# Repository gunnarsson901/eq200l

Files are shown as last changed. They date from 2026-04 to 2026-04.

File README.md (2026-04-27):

```
  ███████╗ ██████╗    ██████╗  ██████╗  ██████╗ ██╗     
  ██╔════╝██╔═══██╗  ╚════██╗██╔═══██╗██╔═══██╗██║     
  █████╗  ██║   ██║   █████╔╝██║   ██║██║   ██║██║     
  ██╔══╝  ██║▄▄ ██║  ██╔═══╝ ██║   ██║██║   ██║██║     
  ███████╗╚██████╔╝  ███████╗╚██████╔╝╚██████╔╝███████╗
  ╚══════╝ ╚══▀▀═╝   ╚══════╝ ╚═════╝  ╚═════╝ ╚══════╝
                 Passive Ethernet Network Tap
```

---

## Introduction

**EQ200L** is a hardware + firmware project for building a passive, transparent Ethernet network tap. Traffic flowing between two network endpoints passes through the device unmodified. The FPGA sits in-line, captures a copy of every frame in both directions, and feeds it to a Raspberry Pi for processing and analysis.

The system uses LAN8720 PHY breakouts for Ethernet connectivity, exposes a menu-driven OLED interface on the Pi, and includes a LoRa radio link for wireless data relay.

**Hardware progression:**

| Stage | FPGA | Host Pi | Notes |
|---|---|---|---|
| Testing | Olimex iCE40HX8K-EVB | Pi Zero 2W | Pi Zero 2W RAM too limited for on-device builds |
| **Current** | **iCeSugar Pro (ECP5)** | **Raspberry Pi 4** | Build and flash from Pi 4 over USB |
| Target | iCeSugar Pro (ECP5) | CM4 8GB, 0GB eMMC | Final embedded form factor |

---

## File Tree

```
eq200l/
├── README.md                         ← you are here
│
├── ICE/                              ← FPGA designs & toolchain
│   ├── install.sh                    ← toolchain installer
│   ├── requirements.txt              ← Python deps for build scripts
│   ├── lib/                          ← reusable Verilog modules
│   │   ├── async_fifo.v
│   │   ├── bram_fifo.v
│   │   ├── cdc_sync.v
│   │   ├── rmii_rx.v                 ← RMII dibit → byte stream
│   │   ├── rmii_tx.v                 ← byte stream → RMII dibit
│   │   ├── spi_slave.v               ← SPI interface to Pi
│   │   ├── sync_fifo.v
│   │   └── uart_tx.v
│   │
│   ├── olimex-ice40hx8k/             ← iCE40HX8K-EVB board target
│   │   ├── hw/                       ← basic design: RMII rx → UART tx
│   │   │   ├── src/top.v
│   │   │   ├── top.pcf
│   │   │   └── Makefile
│   │   ├── sim/                      ← testbench for hw/
│   │   │   ├── src/  tb/  sim/
│   │   │   └── Makefile
│   │   └── projects/
│   │       ├── blink_button/
│   │       ├── spi_message/          ← SPI comms demo
│   │       └── eq200l/               ← dual-port tap (main project)
│   │           ├── src/
│   │           ├── top.pcf
│   │           └── Makefile
│   │
│   └── icesugar-pro/                 ← ECP5 iCeSugar Pro board target
│       ├── hw/                       ← 25 MHz single-clock tap
│       │   ├── src/top.v
│       │   ├── top.lpf
│       │   └── Makefile
│       ├── sim_tap/                  ← full tap sim with SMI interface
│       │   ├── src/  tb/
│       │   └── Makefile
│       └── docs/
│           ├── README.md             ← SODIMM-200P pinout table
│           └── wiring.md             ← LAN8720 ↔ FPGA connections
│
├── PI/                               ← Raspberry Pi software
│   └── interface/                    ← OLED menu UI
│       ├── main.py                   ← scrollable menu application
│       ├── display.py                ← SSD1309 I2C driver
│       ├── buttons.py                ← GPIO button polling + debounce
│       ├── requirements.txt          ← luma.oled, RPi.GPIO, Pillow
│       └── TEST/                     ← unit tests
│
├── LoRa/                             ← LoRa wireless subsystem
│   ├── lora_terminal.py              ← UART ↔ LoRa bridge terminal
│   ├── probe.py                      ← DX-LR20 chip probe utility
│   └── docs/                         ← datasheets & module info
│
└── docs/                             ← hardware documentation
    ├── eq200l schematics/            ← project schematics
    ├── icesugar-pro/                 ← ECP5 board docs & pinout image
    ├── ice40hx8k/                    ← iCE40 board docs
    ├── LAN8720 ETH Board/            ← PHY datasheet
    ├── LoRa/                         ← LoRa module docs
    └── examen arbete YRGO/           ← exam work archive
```

---

## System Flow

```mermaid
flowchart LR
    A([Port A\nRJ45]) <-->|Ethernet| PHY_A[LAN8720\nPHY A]
    B([Port B\nRJ45]) <-->|Ethernet| PHY_B[LAN8720\nPHY B]

    PHY_A <-->|RMII| FPGA
    PHY_B <-->|RMII| FPGA

    subgraph FPGA [FPGA  iCE40 / ECP5]
        direction TB
        FWD[Transparent\nForwarding]
        BUF[(Frame\nCapture FIFO)]
        FWD -->|tap copy| BUF
    end

    FPGA <-->|SPI / SMI| PI[Raspberry Pi 4\n→ CM4 target]

    PI --> OLED[SSD1309\nOLED 128×64]
    PI <-->|GPIO| BTN[5-Button\nNavpad]
    PI <-->|UART| LORA[DX-LR20\nLoRa 433 MHz]

    LORA -.->|wireless| REMOTE([Remote Node])
```

---

## Features

### FPGA Core

| Feature | Status |
|---|---|
| Transparent dual-port Ethernet forwarding | Implemented |
| RMII frame capture — iCE40HX8K target | Implemented |
| RMII frame capture — ECP5 iCeSugar Pro target | Implemented |
| Frame capture FIFO (BRAM-backed) | Implemented |
| Packet filtering in FPGA | TBI |

### Host Interface

| Feature | Status |
|---|---|
| UART frame output to host | Implemented |
| SPI slave interface to Pi | Implemented |
| SMI high-bandwidth interface to Pi | TBI |
| SMI DMA burst transfers | TBI |

### Toolchain & Build

| Feature | Status |
|---|---|
| FPGA flash via Pi SPI + flashrom (iCE40) | Implemented |
| FPGA flash via openFPGALoader (ECP5) | Implemented |
| iverilog simulation + GTKWave waveforms | Implemented |
| ice.sh CLI workflow menu | Implemented |

### User Interface

| Feature | Status |
|---|---|
| SSD1309 OLED menu UI (128×64, I2C) | Implemented |
| 5-button navigation with debounce | Implemented |
| Web interface for captured traffic | TBI |

### Wireless

| Feature | Status |
|---|---|
| LoRa UART bridge terminal | Implemented |
| LoRa chip probe / configuration utility | Implemented |
| Wireless streaming of captures via LoRa | TBI |

### Software / Analysis

| Feature | Status |
|---|---|
| Pi-side frame decoder / pcap export | TBI |

### Hardware Platform

| Milestone | Status |
|---|---|
| iCE40HX8K-EVB + Pi Zero 2W (initial testing) | Implemented |
| iCeSugar Pro (ECP5) + Raspberry Pi 4 (current) | Implemented |
| CM4 8GB RAM, 0GB eMMC — final form factor | TBI |

---

## Devices

### FPGA — iCeSugar Pro (ECP5) — *current board*

Lattice ECP5 FPGA on a compact module with a DDR-SODIMM-200P edge connector and a
built-in iCELink DAPLink USB adapter (`0x0d28:0x0204`). Programmed via
`openFPGALoader --cable cmsisdap` directly from the Pi 4 over USB — no SPI
programmer needed.

## DDR-SODIMM-200P
| Function | Top-Pin | Bot-Pin | Function |
|---|---|---|---|
| GND | 1 | 2 | 5V |
| GND | 3 | 4 | 5V |
| GND | 5 | 6 | 5V |
| GND | 7 | 8 | 5V |
| GND | 9 | 10 | 5V |
| GND | 11 | 12 | 5V |
| NC | 13 | 14 | NC |
| NC | 15 | 16 | NC |
| NC | 17 | 18 | NC |
| NC | 19 | 20 | NC |
| NC | 21 | 22 | NC |
| NC | 23 | 24 | NC |
| NC | 25 | 26 | NC |
| NC | 27 | 28 | NC |
| NC | 29 | 30 | NC |
| NC | 31 | 32 | NC |
| NC | 33 | 34 | NC |
| NC | 35 | 36 | NC |
| NC | 37 | 38 | NC |
| GND | 39 | 40 | GND |
| | | | |
| | | | |
| A8 | 41 | 42 | P11 |
| NC | 43 | 44 | P12 |
| NC | 45 | 46 | N12 |
| NC | 47 | 48 | P13 |
| B8 | 49 | 50 | N13 |
| A7 | 51 | 52 | P14 |
| NC | 53 | 54 | M12 |
| GND | 55 | 56 | GND |
| B7 | 57 | 58 | M13 |
| A6 | 59 | 60 | L14 |
| B6 | 61 | 62 | L13 |
| A5 | 63 | 64 | K14 |
| B5 | 65 | 66 | K13 |
| A4 | 67 | 68 | J14 |
| B4 | 69 | 70 | J13 |
| A3 | 71 | 72 | H14 |
| B3 | 73 | 74 | H13 |
| A2 | 75 | 76 | G14 |
| B1 | 77 | 78 | G13 |
| B2 | 79 | 80 | F14 |
| C1 | 81 | 82 | F13 |
| C2 | 83 | 84 | E14 |
| D1 | 85 | 86 | E13 |
| D3 | 87 | 88 | E12 |
| E1 | 89 | 90 | C13 |
| E2 | 91 | 92 | D13 |
| F1 | 93 | 94 | C12 |
| F2 | 95 | 96 | D12 |
| G1 | 97 | 98 | C11 |
| G2 | 99 | 100  | D11 |
| H2 | 101  | 102  | C10 |
| J1 | 103  | 104  | D10 |
| GND | 105  | 106  | GND |
| GND | 107  | 108  | GND |
| J2 | 109  | 110  | C9 |
| K1 | 111  | 112  | D9 |
| K2 | 113  | 114  | C8 |
| L1 | 115  | 116  | D8 |
| L2 | 117  | 118  | C7 |
| M1 | 119  | 120  | D7 |
| M2 | 121  | 122  | C6 |
| N1 | 123  | 124  | D6 |
| N3 | 125  | 126  | C5 |
| P1 | 127  | 128  | D5 |
| P2 | 129  | 130  | C4 |
| R1 | 131  | 132  | D4 |
| R2 | 133  | 134  | C3 |
| T2 | 135  | 136  | E4 |
| R3 | 137  | 138  | E3 |
| T3 | 139  | 140  | F4 |
| R4 | 141  | 142  | F3 |
| T4 | 143  | 144  | G4 |
| R5 | 145  | 146  | G3 |
| R6 | 147  | 148  | H3 |
| T6 | 149  | 150  | J4 |
| P7 | 151  | 152  | J3 |
| R7 | 153  | 154  | K4 |
| R8 | 155  | 156  | K3 |
| GND | 157  | 158  | GND |
| NC | 159  | 160  | NC |
| NC | 161  | 162  | NC |
| NC | 163  | 164  | NC |
| NC | 165  | 166  | NC |
| NC | 167  | 168  | NC |
| NC | 169  | 170  | NC |
| NC | 171  | 172  | NC |
| NC | 173  | 174  | NC |
| NC | 175  | 176  | NC |
| NC | 177  | 178  | NC |
| NC | 179  | 180  | NC |
| NC | 181  | 182  | NC |
| NC | 183  | 184  | NC |
| NC | 185  | 186  | NC |
| NC | 187  | 188  | NC |
| NC | 189  | 190  | NC |
| NC | 191  | 192  | NC |
| NC | 193  | 194  | NC |
| NC | 195  | 196  | NC |
| NC | 197  | 198  | NC |
| GND | 199  | 200  | GND |

## Ext-Board Pin map
the Ext-Board is origin designed for Colorlight i5 module, in [Colorlight-FPGA-Projects](https://github.com/wuxx/Colorlight-FPGA-Projects), there is a on-board DAPLink to do the flash work, the iCESugar-Pro doesn't need it, so the Ext-Board actually is a "real" breakout board.  
iCESugar-pro-pinmap

### Notes
Please note that some pins of P5 are shared with Ext-Board DAPLink, include {D12, C11, D13, C12, E12, C13, E14, E13}, if you have enough pins, just don't use these pins. if you want to use these pins, one simple way is force the Ext-Board DAPLink run into bootloader. just create a file named `START_BL.ACT` in root directory of DAPLink. for example, type `$cd /media/pi/DAPLink && touch START_BL.ACT`

> `icesprog` does **not** work with the iCELink firmware — it expects VID `0x1d50`.
> Use `openFPGALoader` instead.

**Toolchain:** `yosys` → `nextpnr-ecp5` → `ecppack` → `openFPGALoader`

**udev rule (run once on the host Pi):**
```bash
sudo tee /etc/udev/rules.d/99-icesugar.rules <<'EOF'
SUBSYSTEM=="usb", ATTRS{idVendor}=="0d28", ATTRS{idProduct}=="0204", MODE="0666", GROUP="plugdev"
SUBSYSTEM=="hidraw", ATTRS{idVendor}=="0d28", ATTRS{idProduct}=="0204", MODE="0666", GROUP="plugdev"
EOF
sudo udevadm control --reload-rules && sudo udevadm trigger
```

See [`ICE/icesugar-pro/docs/wiring.md`](ICE/icesugar-pro/docs/wiring.md) for LAN8720 ↔ ECP5 pin connections.

---

### FPGA — Olimex iCE40HX8K-EVB — *legacy / testing*

Used during initial development. Houses a Lattice iCE40HX8K in a CT256 BGA package.
Programmed via Pi SPI using `flashrom`; the same SPI lines double as the runtime
data path (`spi_slave.v`). Superseded by the iCeSugar Pro for active development.

**Toolchain:** `yosys` → `nextpnr-ice40` → `icepack` → `flashrom`

| Onboard signal | Net | FPGA pin |
|---|-----|---|
| 100 MHz clock | `CLK` | J3 |
| LED 1 | `LED1` | M12 |
| LED 2 | `LED2` | R16 |
| Button 1 | `BUT1` | K11 |
| Button 2 | `BUT2` | P13 |

**RMII connections (LAN8720 ↔ iCE40)**

| Signal | LAN8720 pin | Verilog net | FPGA pin |
|---|---|---|---|
| 50 MHz ref clock | nINT/RETCLK | `pio3_00` | E4 (GBIN) |
| RX data 0 | RXD0 | `pio3_01` | B2 |
| RX data 1 | RXD1 | `pio3_08` | G5 |
| Carrier sense | CRS_DV | `pio3_07` | D2 |
| TX enable | TX_EN | `pio3_02` | F5 |
| TX data 0 | TXD0 | `pio3_09` | D1 |
| TX data 1 | TXD1 | `pio3_03` | B1 |
| Management data | MDIO | `pio3_04` | C1 |
| Management clock | MDC | `pio3_06` | F4 |

**SMI interface (iCE40 ↔ Pi GPIO)**

| Signal | Pi GPIO (BCM) | Verilog net | FPGA pin |
|---|---|---|---|
| SMI Data 0 | 8 | `pio3_15` | F3 |
| SMI Data 1 | 9 | `pio3_16` | H3 |
| SMI Data 2 | 10 | `pio3_17` | F2 |
| SMI Data 3 | 11 | `pio3_18` | H6 |
| SMI Data 4 | 12 | `pio3_19` | F1 |
| SMI Data 5 | 13 | `pio3_20` | H4 |
| SMI Data 6 | 14 | `pio3_21` | G2 |
| SMI Data 7 | 15 | `pio3_22` | J4 |
| SMI Address 0 | 0 | `pio3_23` | G1 |
| SMI Address 1 | 1 | `pio3_24` | J3 |
| SMI Read (SOE) | 18 | `pio3_25` | G3 |
| SMI Write (SWE) | 19 | `pio3_26` | K3 |

---

### Ethernet PHY — LAN8720

Low-power 10/100 Ethernet transceiver in a small breakout module. Provides the
RMII interface (2-bit data, 50 MHz reference clock) between the RJ45 jack and
the FPGA. Two modules are used — one for each network port.

Key signals: `RXD[1:0]`, `CRS_DV`, `TXD[1:0]`, `TX_EN`, `REF_CLK`, `MDIO`, `MDC`.

---

### Host — Raspberry Pi 4 *(current)* → CM4 8GB, 0GB eMMC *(target)*

Runs the user-space software: reads captured frames from the FPGA over SPI (or
SMI), drives the OLED display, handles button input, and bridges data to LoRa.
Also acts as the FPGA programmer — `openFPGALoader` programs the iCeSugar Pro
directly over USB from the Pi 4.

The Pi Zero 2W was used during initial testing but its limited RAM made
on-device synthesis impractical. The Pi 4 is the current development host.
The final target is a **Compute Module 4 (8GB RAM, 0GB eMMC / Lite)** for a
compact embedded form factor.

**Pi 40-pin header — signals used by this project**

| Pin | BCM | Function |
|-----|-----|---|
| 8 | 14 | UART TXD / SMI Data 6 → FPGA G2 |
| 10 | 15 | UART RXD / SMI Data 7 → FPGA J4 |
| 12 | 18 | SMI Read SOE → FPGA G3 |
| 19 | 10 | SPI0 MOSI / SMI Data 2 → FPGA P11 |
| 21 | 9 | SPI0 MISO / SMI Data 1 → FPGA P12 |
| 23 | 11 | SPI0 CLK / SMI Data 3 → FPGA R11 |
| 24 | 8 | SPI0 CE0 / SMI Data 0 → FPGA R12 |
| 27 | 0 | ID_SDA / SMI SA0 → FPGA G1 |
| 28 | 1 | ID_SCL / SMI SA1 → FPGA J3 |
| 32 | 12 | SMI Data 4 → FPGA F1 |
| 33 | 13 | SMI Data 5 → FPGA H4 |
| 35 | 19 | SPI1 MISO / SMI Write SWE → FPGA K3 |

> SPI0 pins serve double duty: `flashrom` uses them to program the FPGA flash at
> boot time; `spi_slave.v` reuses the same lines at runtime to stream frame bytes.

---

### Display — SSD1309 OLED (128 × 64)

Monochrome OLED display connected to the Pi over I2C. Driven by `luma.oled` +
Pillow. The UI (`PI/interface/main.py`) renders a scrollable 5-item menu with a
dynamic scrollbar and handles up/down/left/right/select navigation.

---

### Wireless — DX-LR20-433M22SP (LoRa)

433 MHz LoRa module connected to the Pi via UART. `LoRa/lora_terminal.py`
provides a threaded UART ↔ LoRa bridge terminal. `LoRa/probe.py` can query and
configure the module's registers.

---

## Workflow

Use the interactive CLI menu to build, flash, and monitor:

```bash
cd ICE
./ice.sh
```

| Option | Action |
|---|---|
| `1` Build | rsync sources → Pi, run `make` (yosys → nextpnr → icepack) |
| `2` Upload | pad bitstream to 2 MB → `flashrom` via SPI |
| `3` Build + Upload | both in sequence |
| `4` Simulate | run iverilog locally; sim_tap has sub-menu |
| `5` Open waves | launch GTKWave with saved VCD |
| `6` Monitor UART | stream FPGA UART output as hex dump from Pi |
| `7` Switch project | `hw` / `sim` / `sim_tap` |
| `8` Settings | Pi host, SPI device, UART device, baud rate |

**Manual UART monitor on Pi:**
```bash
stty -F /dev/ttyS0 1000000 raw -echo cs8 -cstopb -parenb
cat /dev/ttyS0 | xxd
```

**Flash ECP5 manually:**
```bash
openFPGALoader --cable cmsisdap --detect
openFPGALoader --cable cmsisdap bitstream.bit
```

---

## Useful Links

| Resource | URL |
|---|-----|
| Olimex iCE40HX8K-EVB wiki | https://wiki.olimex.com/wiki/ICE40HX8K-EVB |
| iCESugar Pro GitHub | https://github.com/wuxx/icesugar-pro |
| Colorlight FPGA Projects (Ext-Board origin) | https://github.com/wuxx/Colorlight-FPGA-Projects |
| Yosys synthesis suite | https://github.com/YosysHQ/yosys |
| nextpnr place-and-route | https://github.com/YosysHQ/nextpnr |
| Project Trellis (ECP5 bitstream) | https://github.com/YosysHQ/prjtrellis |
| openFPGALoader | https://github.com/trabucayre/openFPGALoader |
| luma.oled Python driver | https://luma-oled.readthedocs.io |
| LAN8720 datasheet | https://ww1.microchip.com/downloads/en/DeviceDoc/00002165B.pdf |
| iCE40 LP/HX family datasheet | `ICE/docs/iCE40LPHXFamilyDataSheet.pdf` (local) |

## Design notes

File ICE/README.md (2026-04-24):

# ICE — FPGA Designs

See the main project documentation: [../../README.md](../README.md)

Pin tables, toolchain instructions, workflow, and device descriptions are all in the root README.

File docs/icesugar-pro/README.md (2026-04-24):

# iCESugar Pro — Hardware Docs

SODIMM-200P pinout and Ext-Board pin map reference.

See the main project documentation: [../../README.md](../../README.md)

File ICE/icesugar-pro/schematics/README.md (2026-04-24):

# iCESugar Pro — Schematics

SODIMM-200P connector pinout reference for the iCESugar Pro breakout board.

See the main project documentation: [../../../../README.md](../../../../README.md)

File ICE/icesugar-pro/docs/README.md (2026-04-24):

# iCESugar Pro — Docs

SODIMM-200P pinout table and Ext-Board pin map for the iCESugar Pro module.

See the main project documentation: [../../../../README.md](../../../../README.md)

For LAN8720 wiring specific to this board, see [wiring.md](wiring.md).

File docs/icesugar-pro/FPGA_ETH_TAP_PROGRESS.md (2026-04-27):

# FPGA Ethernet Tap — Development Log

## Hardware

- iCESugar Pro (LFE5U-25F-6CABGA256 ECP5) on BRB carrier board
- Two LAN8720 RMII PHY modules (ETH1 on P2 connector, ETH2 on P3 connector)
- Raspberry Pi 4 connected via SPI (capture readout) and JTAG (bitstream loading)

---

## Issue 1 — ETH2 pin row A/B swapped

**Symptom:** 0 frames captured from ETH2 after initial wiring.

**Root cause:** The 2×7 LAN8720 module connector has B-row pins (REFCLK, CRS_DV, RXD,
TXD) and A-row pins (MDC/MDIO, RXD, TXD). The initial LPF had every signal on the wrong
row — A↔B swapped throughout.

**Correct ETH2 pin mapping (P3 connector on BRB):**

| Signal | FPGA site | LAN8720 pin |
|---|---|---|
| REFCLKO | B7 | nINT/REFCLKO |
| CRS_DV | A7 | CRS_DV |
| RXD[0] | B6 | RXD0 |
| RXD[1] | A6 | RXD1 |
| TX_EN | B5 | TXEN |
| TXD[0] | A5 | TXD0 |
| TXD[1] | B4 | TXD1 |
| MDIO | B8 | MDIO |
| MDC | A8 | MDC |

**Fix:** Updated `ICE/icesugar-pro/hw/top.lpf` with the correct LOCATE COMP entries.

**Verification:** After the fix we got 2 legible frames showing `ff:ff:ff:ff:ff:ff`
broadcast destination — confirming the RX path was alive.

---

## Issue 2 — PLL left in top.v with e2_ref_clk as output

**Symptom:** After a context-compaction rebuild the FPGA had a PLL driving e2_ref_clk as an
*output*, but the LAN8720 XTS 50 MHz crystal is the clock *source* (REFCLKO on B7 drives the
FPGA).

**Root cause:** A previous edit had added an EHXPLLL block to generate 50 MHz, treating
e2_ref_clk as a PLL output. When the LAN8720 is in REFCLKO mode it drives B7; the FPGA
must accept this as an input, not drive it.

**Fix:**
- Removed the EHXPLLL block from `top.v`.
- Changed `output wire e2_ref_clk` → `input wire e2_ref_clk`.
- All ETH2 clock-domain logic now uses `e2_ref_clk` directly (no `clk_50m`).
- Changed `led_b` from `~pll_lock` to `~link_up[1]` (ETH2 link-down indicator).

---

## Issue 3 — LAN8720 CRS_DV demultiplexing causes preamble bytes in frame data

**Symptom:** Captured "frames" contained preamble bytes (0xAA/0x55 patterns) in the
payload, and the SFD (0xD5) was visible inside frame data.

**Root cause:** The LAN8720 demultiplexes CRS (Carrier Sense) and DV (Data Valid) onto the
single CRS_DV pin on *alternate* REFCLKO cycles:
- During preamble (before internal SFD detection): CRS=1, DV=0 → CRS_DV alternates 1/0/1/0
- After SFD detected internally: CRS=1, DV=1 → CRS_DV stays high

The original `rmii_rx` treated a single CRS_DV low as end-of-frame. During the preamble the
alternating lows bounced the state machine back to IDLE mid-preamble, causing it to
re-enter PREAMBLE at a wrong dibit offset. The resulting frame data was a mix of preamble
and real payload.

**Fix applied to `ICE/lib/rmii_rx.v`:**
1. Added `crs_dv_prev` register (one-cycle delayed CRS_DV).
2. Changed all "return to IDLE" checks from `!crs_dv` to `!crs_dv && !crs_dv_prev` — two
   consecutive lows required (real end-of-frame, not the alternating preamble glitch).
3. Removed the `crs_dv` guard from DATA-state dibit collection — collect on every cycle,
   since after the internal SFD CRS_DV is steady; guarding caused 0 frames.
4. Removed the `crs_dv &&` requirement from SFD detection (`rxd == 2'b11`) in PREAMBLE
   state — the LAN8720 may briefly glitch CRS_DV at the preamble→data boundary.

**Status as of last test:** 14 frames captured in 10 s, SOF markers present, data still
shows dibit-alignment artefacts (`3F 00 00 FC` repeating pattern when broadcast FFs expected).
The 2-bit shift is consistent with a 1-dibit SFD boundary error still present — under
active investigation.

---

## SPI capture protocol

The FPGA streams captured Ethernet bytes to the Pi over SPI0 (Mode 0, 500 kHz):

- `0xFF` — idle (cap FIFO empty)
- `0xFE` — start-of-frame marker (inserted by FPGA SPI framer)
- `<N data bytes>` — Ethernet frame content (no explicit end marker; next `0xFE` or `0xFF`
  implies end)

The Pi reads 256-byte bursts with manual CS on GPIO 24.

---

## Remaining work

- Fix the 1-dibit alignment issue in `rmii_rx`: the DATA state appears to collect one
  dibit too early or the SFD dibit (11) is being included in the first data byte.
  Candidate fix: after SFD detection, skip one additional dibit before starting collection,
  or verify the LAN8720 timing of when REFCLKO-aligned data starts relative to the 11 dibit.
- Verify clean frame decode with a known test packet (ARP request, ICMP ping).
- Write captured frames to PCAP file on the Pi for Wireshark analysis.
- Burn to SPI flash (`make upload`) once capture is stable.

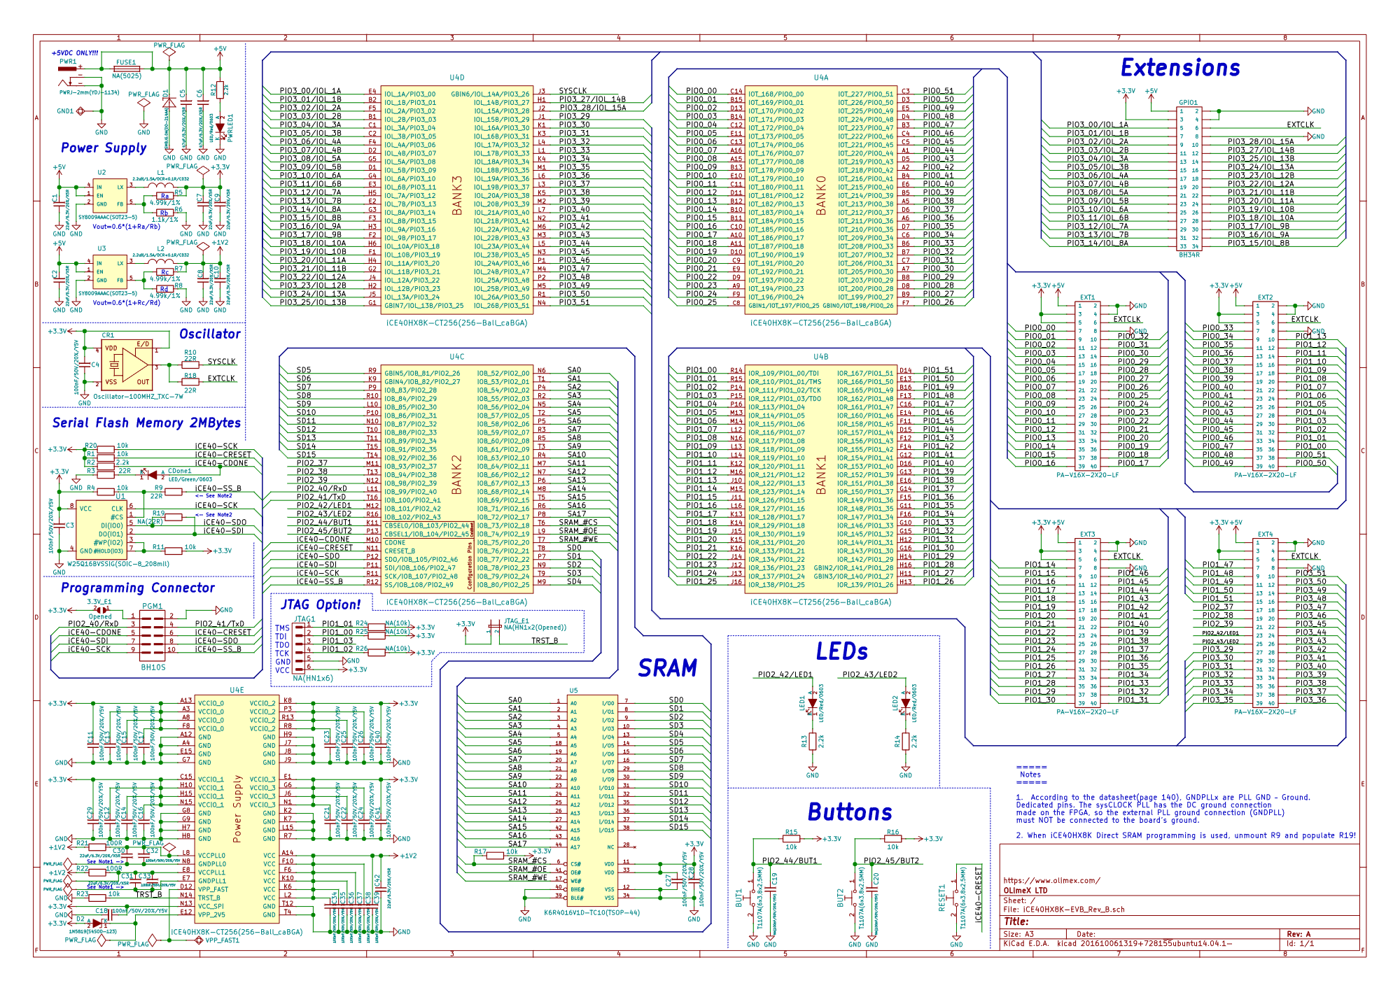
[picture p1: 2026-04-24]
docs/ice40hx8k/download.png

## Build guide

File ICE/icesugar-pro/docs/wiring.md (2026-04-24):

# ICESUGAR-PRO BRB ↔ LAN8720 Ethernet Board

## P2 → ETH1 Connection
| P2 Pin | ETH1 Pin | Signal |
|:---:|:---:|:---:|
| R1 | NC | - |
| P1 | TXD | TX Data |
| N1 | RX1 | RX Data 1 |
| M1 | CRS | Carrier Sense |
| K1 | MDC | Management Data Clock |
| GND | GND | Ground  |
| 3V3 | VCC | Power |
| P2 | TX1 | TX Data 1 |
| N3 | TX_en | TX Enable |
| M2 | RXD | RX Data |
| L2 | nINT/RETCLK | Interrupt/Ref Clock |
| G2 | MDIO | Management Data I/O |

## P3 → ETH2 Connection
| P3 Pin | ETH2 Pin | Signal |
|:---:|:---:|:---:|
| B4 | NC | - |
| B5 | TXD | TX Data |
| B6 | RX1 | RX Data 1 |
| B7 | CRS | Carrier Sense |
| B8 | MDC | Management Data Clock |
| GND | GND | Ground  |
| 3V3 | VCC | Power |
| A4 | TX1 | TX Data 1 |
| A5 | TX_en | TX Enable |
| A6 | RXD | RX Data |
| A7 | nINT/RETCLK | Interrupt/Ref Clock |
| A8 | MDIO | Management Data I/O |

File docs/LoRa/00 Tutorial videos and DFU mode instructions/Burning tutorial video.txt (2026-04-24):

Since the LR20/30 series has two versions, please check your order to confirm the version and refer to the corresponding video for learning how to burn the firmware.

https://youtu.be/hX-SSG80Oh8?si=5gjV5DjxgIYffU_W  《LR20/30 series old model burning tutorial》
https://youtu.be/L_HUamG1tiY?si=bQwIUzYVx_draZ6w  《LR20/30 Series New Burning Tutorial》

Note:
1.This document provides a quick guide on how to quickly verify the functionality of LR20/30 products and a tutorial on burning them.
2.Tutorial for those who cannot enter DFU mode

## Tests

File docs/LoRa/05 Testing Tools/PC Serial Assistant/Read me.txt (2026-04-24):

File Description:
CH341SER driver.EXE is the driver software and must be installed before using UartAssist.exe.

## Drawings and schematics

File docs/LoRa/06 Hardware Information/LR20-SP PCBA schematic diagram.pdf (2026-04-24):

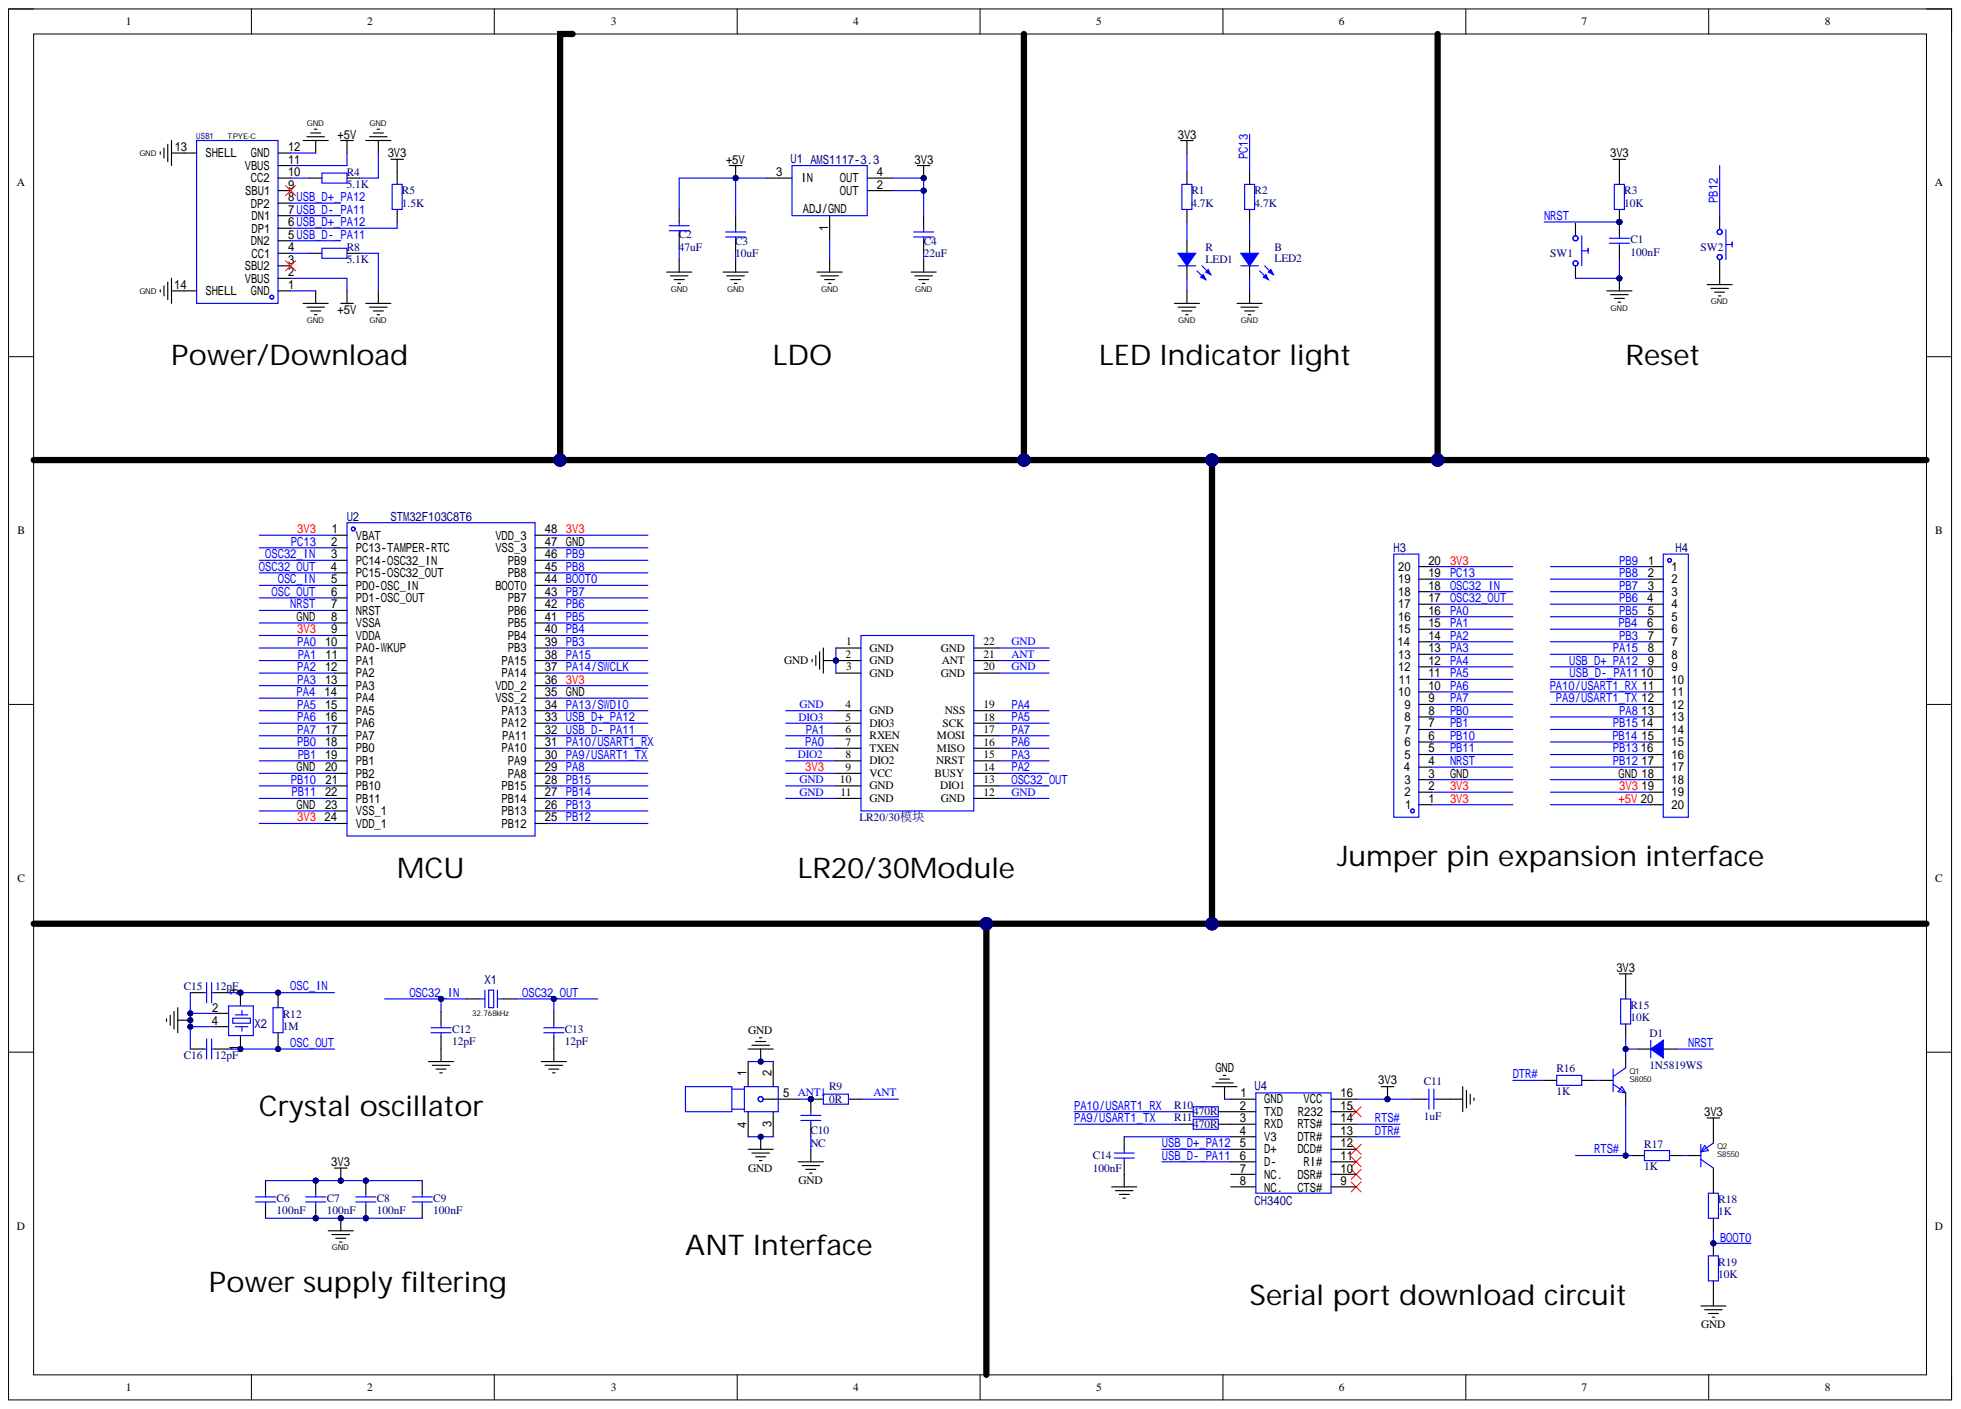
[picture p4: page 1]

Jumper pin expansion interface

Serial port download circuit

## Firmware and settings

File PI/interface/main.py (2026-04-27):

#!/usr/bin/env python3
"""EQ200L — OLED menu interface."""

import os
import socket
import subprocess
import time

try:
    import lgpio as _lgpio
    _LGPIO_OK = True
except ImportError:
    _LGPIO_OK = False

MARAUDER_SPI  = "/dev/spidev0.0"
MARAUDER_GPIO = 24   # ready/IRQ pin

from PIL import Image, ImageDraw, ImageFont

from display import init_display
from buttons import init_buttons, poll, cleanup

try:
    import qrcode
    import qrcode.constants
    HAS_QR = True
except ImportError:
    HAS_QR = False

GITHUB_URL = "https://github.com/gunnarsson901/eq200l"
W, H       = 128, 64
ROW_H      = 11
SPLASH_SEC = 2.5


# ── fonts ─────────────────────────────────────────────────────────────────────

def _font(size=None):
    if size:
        for path in [
            "/usr/share/fonts/truetype/dejavu/DejaVuSansMono-Bold.ttf",
            "/usr/share/fonts/truetype/freefont/FreeMono.ttf",
            "/usr/share/fonts/truetype/liberation/LiberationMono-Bold.ttf",
        ]:
            try:
                return ImageFont.truetype(path, size)
            except OSError:
                continue
    return ImageFont.load_default()


def _text_w(draw, text, font):
    bb = draw.textbbox((0, 0), text, font=font)
    return bb[2] - bb[0]


# ── screens ───────────────────────────────────────────────────────────────────

def draw_splash(device):
    img = Image.new('1', (W, H), 0)
    d   = ImageDraw.Draw(img)
    big = _font(22)
    sm  = _font(9)

    title = "EQ200L"
    tx = (W - _text_w(d, title, big)) // 2
    d.text((tx, 4), title, font=big, fill=255)

    for row, line in enumerate(["Passive Network Tap", "ECP5  x  Pi 4"]):
        lx = (W - _text_w(d, line, sm)) // 2
        d.text((lx, 40 + row * 12), line, font=sm, fill=255)

    device.display(img)
    time.sleep(SPLASH_SEC)


def draw_menu(device, items, cursor, scroll, title=""):
    img  = Image.new('1', (W, H), 0)
    d    = ImageDraw.Draw(img)
    font = _font()
    y0   = 0

    if title:
        d.text((2, 1), title, font=font, fill=255)
        d.line([(0, 11), (W - 1, 11)], fill=255)
        y0 = 13

    vis = (H - y0) // ROW_H

    for i in range(vis):
        idx = scroll + i
        if idx >= len(items):
            break
        item  = items[idx]
        y     = y0 + i * ROW_H
        label = item['label']
        if isinstance(item.get('action'), list):
            label += ' >'
        if idx == cursor:
            d.rectangle([0, y, W - 5, y + ROW_H - 2], fill=255)
            d.text((4, y + 1), label[:20], font=font, fill=0)
        else:
            d.text((4, y + 1), label[:20], font=font, fill=255)

    n = len(items)
    if n > vis:
        bh = max(4, (H - y0) * vis // n)
        ms = max(1, n - vis)
        by = y0 + (H - y0 - bh) * scroll // ms
        d.rectangle([W - 3, by, W - 1, by + bh - 1], fill=255)

    device.display(img)


def draw_lines(device, lines, title=""):
    """Generic scrollable text screen. Any button press returns to menu."""
    img  = Image.new('1', (W, H), 0)
    d    = ImageDraw.Draw(img)
    font = _font()
    y    = 0

    if title:
        d.text((2, 0), title, font=font, fill=255)
        d.line([(0, 10), (W - 1, 10)], fill=255)
        y = 12

    for line in lines:
        if y > H - 10:
            break
        d.text((2, y), str(line)[:21], font=font, fill=255)
        y += 10

    device.display(img)


def draw_qr(device):
    img  = Image.new('1', (W, H), 0)
    d    = ImageDraw.Draw(img)
    font = _font()

    if not HAS_QR:
        draw_lines(device, ["pip install", "  qrcode[pil]"], "Missing: qrcode")
        return

    qr = qrcode.QRCode(
        version=None,
        error_correction=qrcode.constants.ERROR_CORRECT_L,
        box_size=2,
        border=1,
    )
    qr.add_data(GITHUB_URL)
    qr.make(fit=True)

    qr_img = qr.make_image().convert('1')
    qr_img = qr_img.resize((H, H), Image.NEAREST)
    img.paste(qr_img, (0, 0))

    for row, text in enumerate(["GitHub:", "", "gunnarsson", "901/eq200l", "", "any key back"]):
        d.text((68, 2 + row * 10), text, font=font, fill=255)

    device.display(img)


# ── system info ───────────────────────────────────────────────────────────────

def _device_info():
    out = []

    try:
        out.append(f"Host:{socket.gethostname()}")
    except Exception:
        out.append("Host: ?")

    try:
        s = socket.socket(socket.AF_INET, socket.SOCK_DGRAM)
        s.settimeout(0.1)
        s.connect(("10.255.255.255", 1))
        out.append(f"IP:  {s.getsockname()[0]}")
        s.close()
    except Exception:
        out.append("IP:  --")

    try:
        model = open("/proc/device-tree/model").read().strip('\x00')
        out.append(model[:21])
    except Exception:
        out.append("HW:  unknown")

    try:
        secs    = float(open("/proc/uptime").read().split()[0])
        m, s    = divmod(int(secs), 60)
        h, m    = divmod(m, 60)
        out.append(f"Up:  {h}h {m:02d}m {s:02d}s")
    except Exception:
        out.append("Up:  ?")

    return out


def _connections():
    out = []

    for iface in ['eth0', 'wlan0', 'usb0']:
        try:
            r = subprocess.run(
                ['ip', '-4', 'addr', 'show', iface],
                capture_output=True, text=True, timeout=2,
            )
            if 'inet ' in r.stdout:
                ip = next(
                    ln.strip().split()[1]
                    for ln in r.stdout.splitlines() if 'inet ' in ln
                )
                out.append(f"{iface}:{ip.split('/')[0]}")
            else:
                out.append(f"{iface}: down")
        except Exception:
            continue

    try:
        r = subprocess.run(['lsusb'], capture_output=True, text=True, timeout=2)
        fpga = "iCeSugar OK" if '0d28:0204' in r.stdout else "not found"
        out.append(f"FPGA:{fpga}")
    except Exception:
        out.append("FPGA: ?")

    for dev in ['/dev/ttyUSB0', '/dev/ttyACM0', '/dev/ttyAMA0', '/dev/ttyS0']:
        if os.path.exists(dev):
            out.append(f"LoRa:{dev}")
            break
    else:
        out.append("LoRa: no dev")

    return out


def _marauder_status():
    out = []

    spi_ok = os.path.exists(MARAUDER_SPI)
    out.append(f"SPI: {'OK' if spi_ok else 'not found'}")

    if _LGPIO_OK:
        try:
            h   = _lgpio.gpiochip_open(0)
            _lgpio.gpio_claim_input(h, MARAUDER_GPIO, _lgpio.SET_PULL_UP)
            val = _lgpio.gpio_read(h, MARAUDER_GPIO)
            _lgpio.gpiochip_close(h)
            out.append(f"GPIO{MARAUDER_GPIO}: {'HI' if val else 'LO'}")
        except Exception:
            out.append(f"GPIO{MARAUDER_GPIO}: err")
    else:
        out.append("lgpio: missing")

    try:
        r = subprocess.run(
            ['ls', '/sys/bus/spi/devices/'],
            capture_output=True, text=True, timeout=2,
        )
        devs = r.stdout.strip().split()
        out.append(f"SPI devs:{len(devs)}")
    except Exception:
        pass

    return out


# ── action helpers ────────────────────────────────────────────────────────────

def _tbi():
    return ('lines', ["Not yet", "implemented."], "TBI")


def _hint(title, *lines):
    return ('lines', list(lines), title)


# ── menu tree ─────────────────────────────────────────────────────────────────

def build_menu():
    return [
        {'label': 'Capture', 'action': [
            {'label': 'UART Monitor',
             'action': lambda: _hint(
                 "UART Monitor",
                 "stty /dev/ttyS0",
                 " 1000000 raw -echo",
                 "cat /dev/ttyS0|xxd",
             )},
            {'label': 'Start Capture',  'action': _tbi},
            {'label': 'Stop Capture',   'action': _tbi},
            {'label': 'Pcap Export',    'action': _tbi},
        ]},
        {'label': 'FPGA', 'action': [
            {'label': 'Flash Bitstream',
             'action': lambda: _hint(
                 "Flash FPGA",
                 "openFPGALoader",
                 " --cable cmsisdap",
                 " bitstream.bit",
             )},
            {'label': 'Detect Device',
             'action': lambda: _hint(
                 "Detect FPGA",
                 "openFPGALoader",
                 " --cable cmsisdap",
                 " --detect",
             )},
        ]},
        {'label': 'LoRa', 'action': [
            {'label': 'Terminal',
             'action': lambda: _hint(
                 "LoRa Terminal",
                 "python3 LoRa/",
                 " lora_terminal.py",
             )},
            {'label': 'Probe',
             'action': lambda: _hint(
                 "LoRa Probe",
                 "python3 LoRa/",
                 " probe.py",
             )},
            {'label': 'Stream Capture', 'action': _tbi},
        ]},
        {'label': 'Marauder', 'action': [
            {'label': 'WiFi', 'action': [
                {'label': 'Probe Sniff',
                 'action': lambda: _hint(
                     "Probe Sniff",
                     "scanap",
                     " then: sniffprobe",
                 )},
                {'label': 'Beacon Scan',
                 'action': lambda: _hint(
                     "Beacon Scan",
                     "scanap",
                 )},
                {'label': 'Deauth Detect',
                 'action': lambda: _hint(
                     "Deauth Detect",
                     "sniffdeauth",
                 )},
                {'label': 'PMKID Sniff',
                 'action': lambda: _hint(
                     "PMKID Sniff",
                     "sniffpmkid",
                 )},
                {'label': 'Wardriving',
                 'action': lambda: _hint(
                     "Wardriving",
                     "wardrive",
                 )},
            ]},
            {'label': 'Bluetooth', 'action': [
                {'label': 'BLE Scan',
                 'action': lambda: _hint(
                     "BLE Scan",
                     "blescansave",
                 )},
                {'label': 'BT Scan',
                 'action': lambda: _hint(
                     "BT Scan",
                     "btscan",
                 )},
            ]},
            {'label': 'Status',
             'action': lambda: ('lines', _marauder_status(), "Marauder")},
            {'label': 'Update FW',
             'action': lambda: _hint(
                 "Update FW",
                 "Use Web-OTA or",
                 "ESP32Marouder/",
                 "MarauderOTA/",
             )},
        ]},
        {'label': 'Settings', 'action': [
            {'label': 'Device Info',
             'action': lambda: ('lines', _device_info(), "Device Info")},
            {'label': 'Connections',
             'action': lambda: ('lines', _connections(), "Connections")},
            {'label': 'Marauder HW',
             'action': lambda: ('lines', _marauder_status(), "Marauder HW")},
            {'label': 'GitHub QR',
             'action': lambda: ('qr', None, None)},
            {'label': 'Contrast',       'action': _tbi},
        ]},
    ]


# ── main loop ─────────────────────────────────────────────────────────────────

def main():
    device = init_display()
    init_buttons()

    draw_splash(device)

    stack   = [{'items': build_menu(), 'cursor': 0, 'scroll': 0, 'title': 'EQ200L'}]
    overlay = None   # ('lines', lines, title) | ('qr', _, _) | None
    dirty   = True

    def vis_count(title):
        return (H - (13 if title else 0)) // ROW_H

    def on_button(name):
        nonlocal dirty, overlay

        if overlay is not None:
            overlay = None
            dirty   = True
            return

        f     = stack[-1]
        items = f['items']
        vis   = vis_count(f['title'])

        if name == 'up':
            if f['cursor'] > 0:
                f['cursor'] -= 1
                if f['cursor'] < f['scroll']:
                    f['scroll'] = f['cursor']
                dirty = True

        elif name == 'down':
            if f['cursor'] < len(items) - 1:
                f['cursor'] += 1
                if f['cursor'] >= f['scroll'] + vis:
                    f['scroll'] = f['cursor'] - vis + 1
                dirty = True

        elif name in ('right', 'select'):
            item   = items[f['cursor']]
            action = item.get('action')
            if isinstance(action, list):
                stack.append({
                    'items':  action,
                    'cursor': 0,
                    'scroll': 0,
                    'title':  item['label'],
                })
            elif callable(action):
                overlay = action()
            dirty = True

        elif name == 'left':
            if len(stack) > 1:
                stack.pop()
                dirty = True

    try:
        while True:
            poll(on_button)
            if dirty:
                if overlay is not None:
                    kind = overlay[0]
                    if kind == 'lines':
                        draw_lines(device, overlay[1], overlay[2])
                    elif kind == 'qr':
                        draw_qr(device)
                else:
                    f = stack[-1]
                    draw_menu(device, f['items'], f['cursor'],
                              f['scroll'], f['title'])
                dirty = False
            time.sleep(0.02)
    except KeyboardInterrupt:
        pass
    finally:
        device.cleanup()
        cleanup()


if __name__ == '__main__':
    main()

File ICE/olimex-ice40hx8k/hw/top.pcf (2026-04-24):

# =============================================================================
# Pin Constraint File — LAN8720 RMII network tap
# Target: ICE40HX8K-CT256
# Wiring: LAN8720 module on J2 connector (new assignment 2026-04)
# =============================================================================

# Clock — LAN8720 NINT/REFCLK 50 MHz → J3 (GBIN6 / board EXTCLK / pi03_26)
set_io ref_clk    J3   # NINT/REFCLK  50 MHz  (GBIN6)

# RMII inputs (LAN8720 → FPGA)
set_io rxd0       F2   # RX0   dibit 0  (pi03_17)
set_io rxd1       H4   # RX1   dibit 1  (pi03_20)
set_io crs_dv     G2   # CRS             (pi03_21)

# RMII outputs (FPGA → LAN8720, held idle — receive-only tap)
set_io txen       H3   # TX_EN           (pi03_16)
set_io txd0       F1   # TXD0  dibit 0  (pi03_19)
set_io txd1       F3   # TX1   dibit 1  (pi03_15)

# MDIO management bus (MDIO driven idle-high, MDC driven low)
set_io mdc        J4   # MDC             (pi03_22)
set_io mdio_out   H6   # MDIO            (pi03_18)

# SPI slave → Pi (PGM1 header, runtime reuse after CDONE)
set_io -nowarn spi_sck   R11   # Pi GPIO11  SPI0_CLK
set_io -nowarn spi_cs_n  R12   # Pi GPIO8   SPI0_CE0_N
set_io -nowarn spi_miso  P12   # Pi GPIO9   SPI0_MISO

# Board LEDs (status)
set_io led1    M12   # LED1 — toggles each received Ethernet frame
set_io led2    R16   # LED2 — on while FIFO has data (PHY active)

# Clock-alive diagnostics on old freq_test pins (for Logic2 verification)
# These will only toggle if ref_clk (E4) is running.
set_io dbg0    D2    # ref_clk/2^26 ≈ 0.74 Hz @ 50 MHz  (pi03_07)
set_io dbg1    G5    # ref_clk/2^25 ≈ 1.5  Hz @ 50 MHz  (pi03_08)
set_io dbg2    D1    # ref_clk/2^24 ≈ 3    Hz @ 50 MHz  (pi03_09)
set_io dbg3    G4    # rx_valid pulse — fires on each received byte

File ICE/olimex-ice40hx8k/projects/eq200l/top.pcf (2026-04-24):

# eq200l — Dual-port RMII tap pin constraints (iCE40HX8K-CT256)
#
# EXTCLK → J3 (GBIN6 / 50 MHz from PHY module)
set_io clk J3

# ── Port A: router/switch side ────────────────────────────────────────────
# Signal      PIO3 name  FPGA pin
set_io phy_a_mdc     D2   # PIO3_07  MDC
set_io phy_a_crs     G5   # PIO3_08  CRS_DV
set_io phy_a_rxd[1]  D1   # PIO3_09  RX1
set_io phy_a_txd[0]  G4   # PIO3_10  TXD
set_io phy_a_mdio    E3   # PIO3_11  MDIO
set_io phy_a_rxd[0]  H5   # PIO3_12  RXD
set_io phy_a_tx_en   E2   # PIO3_13  TX_EN
set_io phy_a_txd[1]  G3   # PIO3_14  TX1

# ── Port B: target/Pi Ethernet side ──────────────────────────────────────
set_io phy_b_txd[1]  F3   # PIO3_15  TX1
set_io phy_b_tx_en   H3   # PIO3_16  TX_EN
set_io phy_b_rxd[0]  F2   # PIO3_17  RXD
set_io phy_b_mdio    H6   # PIO3_18  MDIO
set_io phy_b_txd[0]  F1   # PIO3_19  TXD
set_io phy_b_rxd[1]  H4   # PIO3_20  RX1
set_io phy_b_crs     G2   # PIO3_21  CRS_DV
set_io phy_b_mdc     J4   # PIO3_22  MDC

# ── LED & Button ─────────────────────────────────────────────────────────
set_io led C2              # PIO3_05  active-high
set_io -pullup yes btn F4  # PIO3_06  active-low

# ── SPI to Pi (programmer header, shared with ICE40 config) ──────────────
set_io -nowarn spi_sck   R11  # Pi GPIO11 SPI0_CLK
set_io -nowarn spi_cs_n  R12  # Pi GPIO8  SPI0_CE0_N
set_io -nowarn spi_miso  P12  # Pi GPIO9  SPI0_MISO

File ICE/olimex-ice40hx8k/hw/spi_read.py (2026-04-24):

#!/usr/bin/env python3
"""
spi_read.py — Read Ethernet frames from FPGA over SPI.

Wire protocol (set by frame_store.v + spi_slave.v):
  The FIFO contains back-to-back frames, each preceded by a 2-byte length:
    [len_h] [len_l] [frame_byte_0] … [frame_byte_N-1]
  where N = (len_h << 8) | len_l  (1 ≤ N ≤ 1518)

  Between frames (FIFO empty) the FPGA returns 0xFF.
  len_h is always 0x00–0x05 (max frame 1518 = 0x05EE), so 0xFF is
  unambiguous as the FIFO-empty sentinel when looking for len_h.

Usage:
  python3 spi_read.py                  # pretty hex dump, one frame at a time
  python3 spi_read.py --raw            # raw framed stream (pipe to spi2pcap.py)
  python3 spi_read.py --dev /dev/spidev0.0   # override SPI device
"""
import spidev, sys, time, argparse, struct

MAX_HZ       = 4_000_000   # 4 MHz — well within Pi SPI capability
DEFAULT_DEV  = "/dev/spidev0.0"   # SPI0 CE0 = GPIO8, MISO = GPIO9, CLK = GPIO11
MAX_FRAMELEN = 1518
POLL_CHUNK   = 64          # bytes per poll burst while hunting for a frame


def open_spi(dev: str, speed: int) -> spidev.SpiDev:
    # /dev/spidevB.C → bus B, device C
    parts = dev.replace("/dev/spidev", "").split(".")
    bus, device = int(parts[0]), int(parts[1])
    spi = spidev.SpiDev()
    spi.open(bus, device)
    spi.max_speed_hz = speed
    spi.mode = 0   # CPOL=0, CPHA=0
    return spi


def read_byte(spi: spidev.SpiDev) -> int:
    return spi.readbytes(1)[0]


def read_exact(spi: spidev.SpiDev, n: int) -> bytes:
    """Read exactly n bytes from SPI (may issue multiple transactions)."""
    buf = bytearray()
    while len(buf) < n:
        want = min(256, n - len(buf))
        buf.extend(spi.readbytes(want))
    return bytes(buf)


def main():
    ap = argparse.ArgumentParser()
    ap.add_argument("--raw",   action="store_true",
                    help="write raw framed bytes to stdout (pipe to spi2pcap.py)")
    ap.add_argument("--speed", type=int, default=MAX_HZ, help="SPI clock Hz")
    ap.add_argument("--dev",   default=DEFAULT_DEV,      help="SPI device path")
    args = ap.parse_args()

    spi = open_spi(args.dev, args.speed)

    frame_no   = 0
    total_b    = 0
    last_stat  = time.monotonic()

    try:
        while True:
            # ── Hunt for len_h ────────────────────────────────────────────────
            # Keep polling until we see a byte in 0x00..0x05 (valid len_h).
            # 0xFF = FIFO empty (skip).  Any other value is a sync error —
            # treat it as FIFO empty and keep hunting.
            len_h = 0xFF
            while len_h == 0xFF or len_h > 5:
                chunk = spi.readbytes(POLL_CHUNK)
                for b in chunk:
                    if b != 0xFF and b <= 5:
                        len_h = b
                        break

            # ── Read len_l (do NOT skip 0xFF — it can be a valid length) ─────
            len_l = read_byte(spi)

            frame_len = (len_h << 8) | len_l
            if frame_len == 0 or frame_len > MAX_FRAMELEN:
                # Spurious framing — skip and re-hunt
                continue

            # ── Read frame data ────────────────────────────────────────────────
            frame = read_exact(spi, frame_len)

            frame_no += 1
            total_b  += frame_len

            if args.raw:
                # Framed format: len_h len_l data[frame_len]
                # spi2pcap.py parses this same format.
                sys.stdout.buffer.write(bytes([len_h, len_l]) + frame)
                sys.stdout.buffer.flush()
            else:
                _hex_dump(frame, frame_no)

            # Periodic stats (hex-dump mode)
            now = time.monotonic()
            if not args.raw and now - last_stat >= 5.0:
                print(f"--- {frame_no} frames  {total_b} bytes ---",
                      file=sys.stderr)
                last_stat = now

    except KeyboardInterrupt:
        print(f"\n--- done: {frame_no} frames  {total_b} bytes ---",
              file=sys.stderr)
    finally:
        spi.close()


def _hex_dump(frame: bytes, no: int):
    etype = struct.unpack_from(">H", frame, 12)[0] if len(frame) >= 14 else 0
    src = ":".join(f"{b:02x}" for b in frame[6:12]) if len(frame) >= 12 else "?"
    dst = ":".join(f"{b:02x}" for b in frame[0:6])  if len(frame) >= 6  else "?"
    print(f"\n── frame {no}  {len(frame)} bytes  "
          f"{dst} ← {src}  ethertype 0x{etype:04x}")
    for i in range(0, len(frame), 16):
        chunk = frame[i:i+16]
        hex_p = " ".join(f"{b:02x}" for b in chunk)
        asc_p = "".join(chr(b) if 32 <= b < 127 else "." for b in chunk)
        print(f"  {i:04x}  {hex_p:<47}  |{asc_p}|")


if __name__ == "__main__":
    main()

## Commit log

2026-04-24 Initial commit — EQ200L passive Ethernet network tap
    FPGA designs (iCE40HX8K + ECP5), Raspberry Pi interface software,
    LoRa wireless bridge, and hardware documentation.
    [DX-LR20&30_PCB_Footprint_AD.PcbDoc, DX-LR20&30_SCH_Part_AD.SchDoc, DX-LR20&30_SCH_Part_PADS.sch]
2026-04-24 docs: update hardware platform and categorise features table
    Reflect current setup: iCeSugar Pro (ECP5) + Raspberry Pi 4.
    Document progression from Pi Zero 2W (RAM too limited for builds)
    through Pi 4 to the CM4 8GB / 0GB eMMC target form factor.
    Add category headings to features table.
2026-04-24 feat(ui): hierarchical menu, boot splash, settings & QR screen
    - Boot splash shows "EQ200L" in large font with hardware subtitle
    - Stack-based menu navigation: right/select enters submenus, left goes back
    - Menu tree mirrors implemented features (Capture, FPGA, LoRa, Settings)
    - TBI items show "not yet implemented"; implemented items show terminal commands
    - Settings > Device Info: hostname, IP, hardware model, uptime
    - Settings > Connections: per-interface IP, FPGA USB detect, LoRa serial port
    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
2026-04-26 build: install icesprog permanently, add program target for Pi-local flashing
    - program: runs icesprog directly on Pi (no SSH loopback)
    - upload/flash: for use from laptop
    - drop sudo and /tmp path — icesprog now at /usr/local/bin
2026-04-26 hw: direction tag + larger capture FIFO
    - cap_fifo: sync_fifo 256×10b → bram_fifo 2048×11b (2× DP16KD EBR)
    fits a full max-size Ethernet frame (1518 B) without overflow
    - phy_bridge: add p3_tx_dir output (0=Pi→Router, 1=Router→Pi)
    - frame_uart: add in_dir input; SOF2 byte is 0x55 (Pi→Router)
    or 0x57 (Router→Pi) so the Pi can tell directions apart
    - Makefile: switch to bram_fifo.v in SRCS; fix .PHONY list
    Wire format after this change:
    Pi→Router frame: 0xAA 0x55 <data> 0xAA 0x56
    Router→Pi frame: 0xAA 0x57 <data> 0xAA 0x56
    Beacon (idle probe): 0xAA 0x55 BEEF 0xAA 0x56
2026-04-26 pi: add capture.py — frame_uart parser and live display
    Parses the 0xAA 0x55/0x57 ... 0xAA 0x56 wire format,
    prints Ethernet header decode + hex dump, optionally writes pcap.
2026-04-26 hw: fix RMII pulldowns + uart_tx pin assignment
    - Add PULLMODE=DOWN to crs_dv and rxd inputs on both PHYs so
    unconnected PHY ports don't flood the capture pipeline
    - Swap uart_tx/uart_rx SITE: uart_tx is B3 (SODIMM 73), not A3
2026-04-26 hw: add MDIO master + PHY link status polling
    - New ICE/lib/mdio_master.v — IEEE 802.3 Clause 22 MDIO master
    (CLK_DIV=12 → MDC ≈ 1 MHz, read-only for now)
    - top.v: two mdio_master instances (one per PHY), poll BSR reg 1
    every 1 s after 100 ms powerup delay; link_up[0/1] updated
    - LEDs now dark when link is down; show RX activity when link is up
    - LPF: e1_mdc=G2, e1_mdio=K1, e2_mdc=A8, e2_mdio=B8
2026-04-27 hw: fix ETH2 pin mapping, remove PLL, improve rmii_rx CRS_DV handling
    - top.lpf: correct all ETH2 A/B row pin assignments — rows were fully
    swapped (REFCLK→B7, CRS_DV→A7, RXD[0]→B6, RXD[1]→A6, TXEN→B5,
    TXD[0]→A5, TXD[1]→B4, MDIO→B8, MDC→A8)
    - top.v: remove EHXPLLL PLL block; e2_ref_clk is now input driven by
    the LAN8720 XTS 50 MHz crystal (REFCLKO output on B7)
    - rmii_rx.v: add crs_dv_prev debounce so single-cycle CRS_DV lows during
    preamble (LAN8720 CRS/DV demux) don't abort the state machine; collect
    dibits unconditionally in DATA state; relax SFD detection to not require
    CRS_DV asserted on the 11 dibit
    - spi_capture.py, spi_test.py, cli.py: Pi-side SPI capt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
    [cli.py, spi_capture.py, spi_test.py]
